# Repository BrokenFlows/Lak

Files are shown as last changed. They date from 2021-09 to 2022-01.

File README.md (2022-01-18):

# Lak
Lak is a 40-key macro ~~pad~~ board

Lak Photo

I primarily type using a small, split, keyboard called [Ishka](https://github.com/BrokenFlows/Ishka).
While very ergonomic, and designed specifically for my hands, it requires two hands to use effectively.
So, I designed Lak for situations where I may have one hand on a mouse and still want to use some keyboard functions.

The stl files in this repository, with the rest of the physical components outlined in the bill of materials, can be used to create a 40-key programmable macroboard.

Lak is a hand-wired keyboard project powered by a [nice!nano](https://nicekeyboards.com/nice-nano) and [ZMK](https://zmk.dev).
Instructions on where to find the shield config, keymap, and a prebuilt `.uf2` can be found in my [zmk-lak repo](https://github.com/BrokenFlows/zmk-lak).

## Instructions

The following instructions will provide details on how to assemble the project as well as covering the materials required.

The [BoM](#Bill-of-Materials) outlines this further, but by way of materials, the project requires some readily available keyboard components, some custom 3D printed components, and a nice!nano microcontroller which (at the time of writing) is available at somewhat frequent but irregular intervals.

The [assembly](#Pre-Wiring) of the project will require some soldering which won't be difficult but may be time-consuming.
If you're new to soldering, I recommend checking out [this YouTube playlist of soldering how-to videos](https://youtube.com/playlist?list=PLYbmtQOxpiujxQlyrUXsafJzl7sxFdSJW).

### Hardware

The [tools](#Tools) and [materials](#Bill-of-Materials) will be used to assemble the final product, shown above. Once you have acquired the items required, you can follow the steps outlined in the [assembly](#Pre-Wiring) section.

#### Tools
- Soldering Iron
- Solder Wire
- 3D Printer/ 3D Printing Service/ or some means of mimicking [the case and parts](./stls/) listed below
- Scissors/ wire cutter
- Glue/ Hot Glue Gun
- Electrical Tape
- **Optional:** wire stripper

#### Bill of Materials
Item # | Quantity | Part Name                                                 | Description
------:|---------:|:----------------------------------------------------------|-------------
1      | 1        | [lak case.stl](./stls/lak_case.stl)                       | The case and integrated switch plate for the keyboard
2      | 1        | [lak sled.stl](./stls/lak_sled.stl)                       | The housing for the nice!nano at the back of the case
3      | 1        | [lak base plate.stl](./stls/lak_base_plate.stl)           | The bottom cover for the keyboard, to protect the wiring once built
4      | 40       | [MX-Style Switches](https://kbdfans.com/collections/gateron-swithes/products/gateron-swtich-3pin-or-5pin?variant=35765200333) | MX-style key switches will serve as the button mechanism
5      | 40       | [MX-Style Keycaps](https://www.adafruit.com/product/5039) | MX-style keycaps, a uniform profile will work best
6      | 40       | [Diodes](https://www.adafruit.com/product/1641)           | Diodes for creating the key matrix
7      | 24       | [Wires](https://www.ebay.ie/itm/232901601951)             | Lengths of insulated solid-core wire to create the key matrix
8      | 1        | [nice!nano](https://nicekeyboards.com/nice-nano)          | The nice!nano microcontroller will serve as the brains of the project and connect to your computer
9      | 1        | [301230 Lithium Polymer Battery](https://www.aliexpress.com/item/33001770863.html) | Optional: LiPo battery to enable wireless usage

The above BoM lists uniform profile keycaps and links to relegendable keycaps. I used a mixture of both of the following in my build:
- [Relgendable MX-Style Keycaps](https://www.adafruit.com/product/5039)
- [DSA Blank Keycaps](https://kbdfans.com/collections/dsa-profile/products/dsa-blank-keycaps-1u-10pcs)

If mixing and matching, or just getting one set, be sure to have 40 keycaps available for your build.

#### 3D Printing
I recommend 3D printing the stl files at the following settings:
Setting         | Value
:---------------|-----:
Filament        | PLA
Nozzle Diameter | < 0.4 mm
Layer Height    | < 0.2 mm
Infill          | 20% <
Supports        | On

#### Pre-Wiring
1. Insert the 40 switches into the case — the top of the switches should be on the shorter side relative to the plate.
2. At this point the keycaps can be placed on top of the switches. If using relegendable keycaps, insert the paper legends before placing the keycaps.

#### Wiring
This guide will go into light detail about the specifics of hand-wiring this keyboard.
This should be sufficient if you're familiar with the process of hand-wiring a keyboard.

The following guides will provide greater detail about the process of hand-wiring, though not the specifics of this board.
These may be helpful if it is your first time hand-wiring a keyboard:

- [QMK Firmware's _Hand-Wiring Guide_](https://github.com/qmk/qmk_firmware/blob/master/docs/hand_wire.md#wiring-the-matrix)
- [RoastPotatoes' _How to hand wire a Plank_](https://blog.roastpotatoes.co/guide/2015/11/04/how-to-handwire-a-planck/#switches)
- [Matt3o.com's _Hand-wiring a custom keyboard_](https://matt3o.com/hand-wiring-a-custom-keyboard/)

---

To start, bend the legs of a diode so that it can hook onto a switch pin and the leg can continue along the row of keys, as seen in the following picture.
Take care to orientate the cathode of the diode (the side marked with a black strip) away from the switch and towards the other diodes.
This is a `col2row` diode direction in the ZMK firmware.

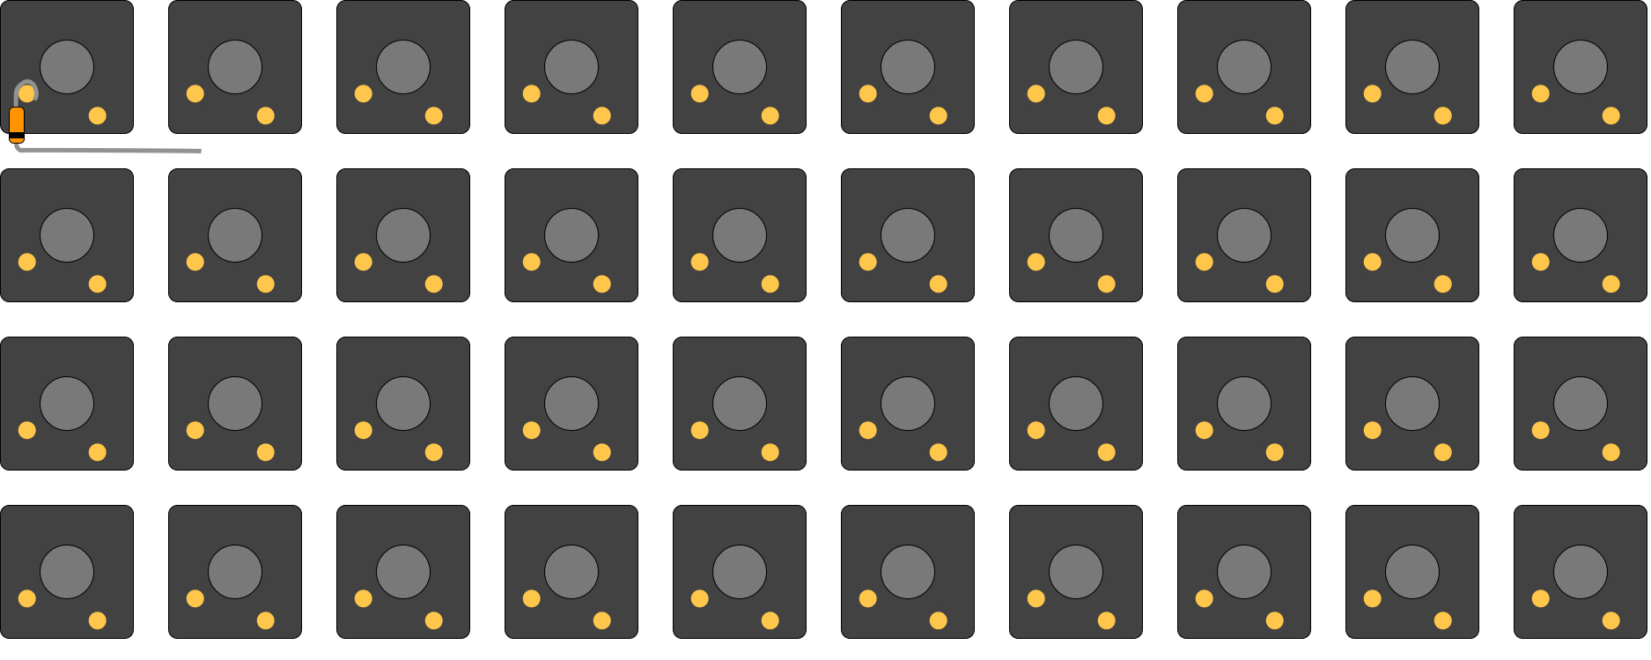
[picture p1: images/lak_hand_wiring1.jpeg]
Picture showing a diode hooked onto a switch pin with one leg while the other leg carries on towards the next switch


At this point solder the diode to the switch pin. Then prepare another diode the same way at the next switch over.

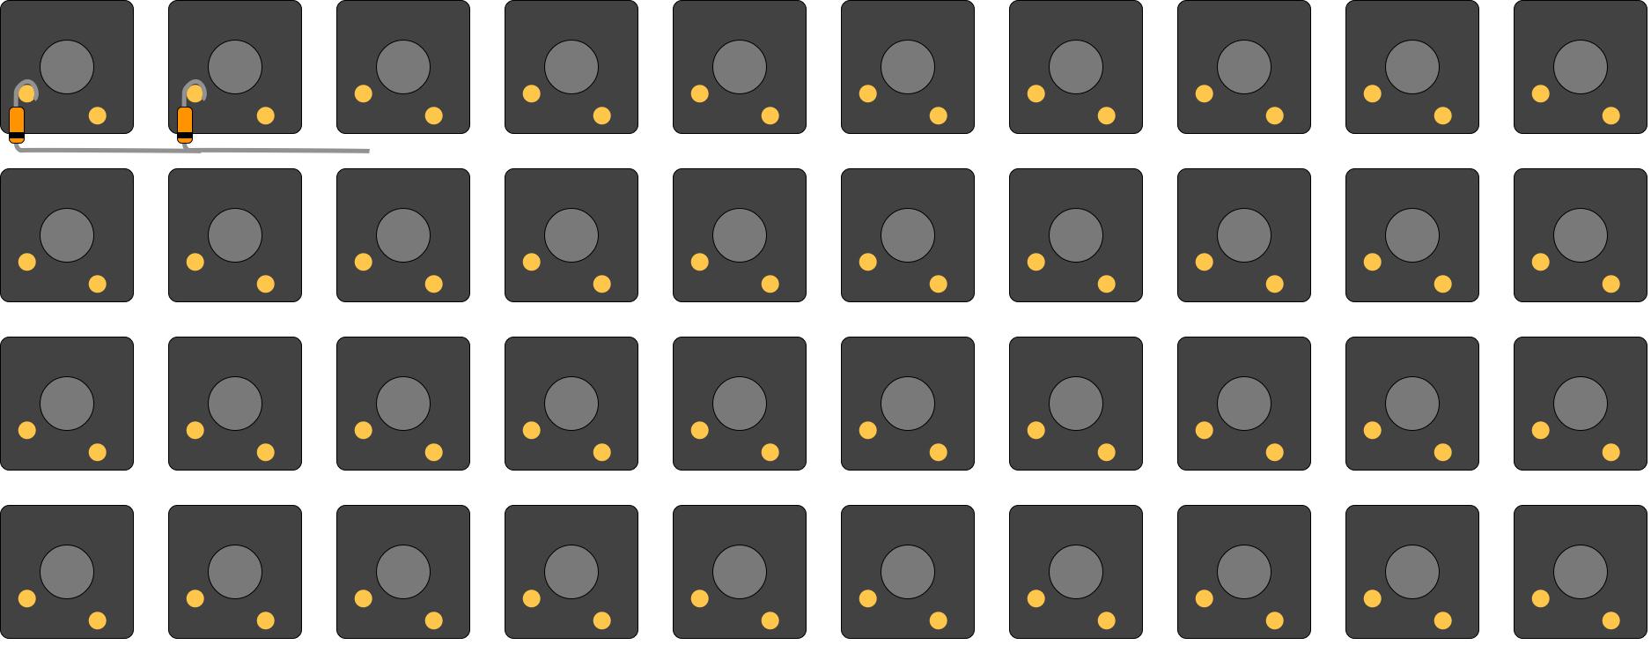
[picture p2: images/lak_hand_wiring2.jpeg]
Picture showing two diodes hooked onto switch pins with one leg while the other leg carries on towards the next switches


Once both switches are soldered to the switch pins, solder the diode legs together along the row where the legs meet.

Carry on, repeating this process until there is one diode connected to each switch and all diodes in a row are connected also.

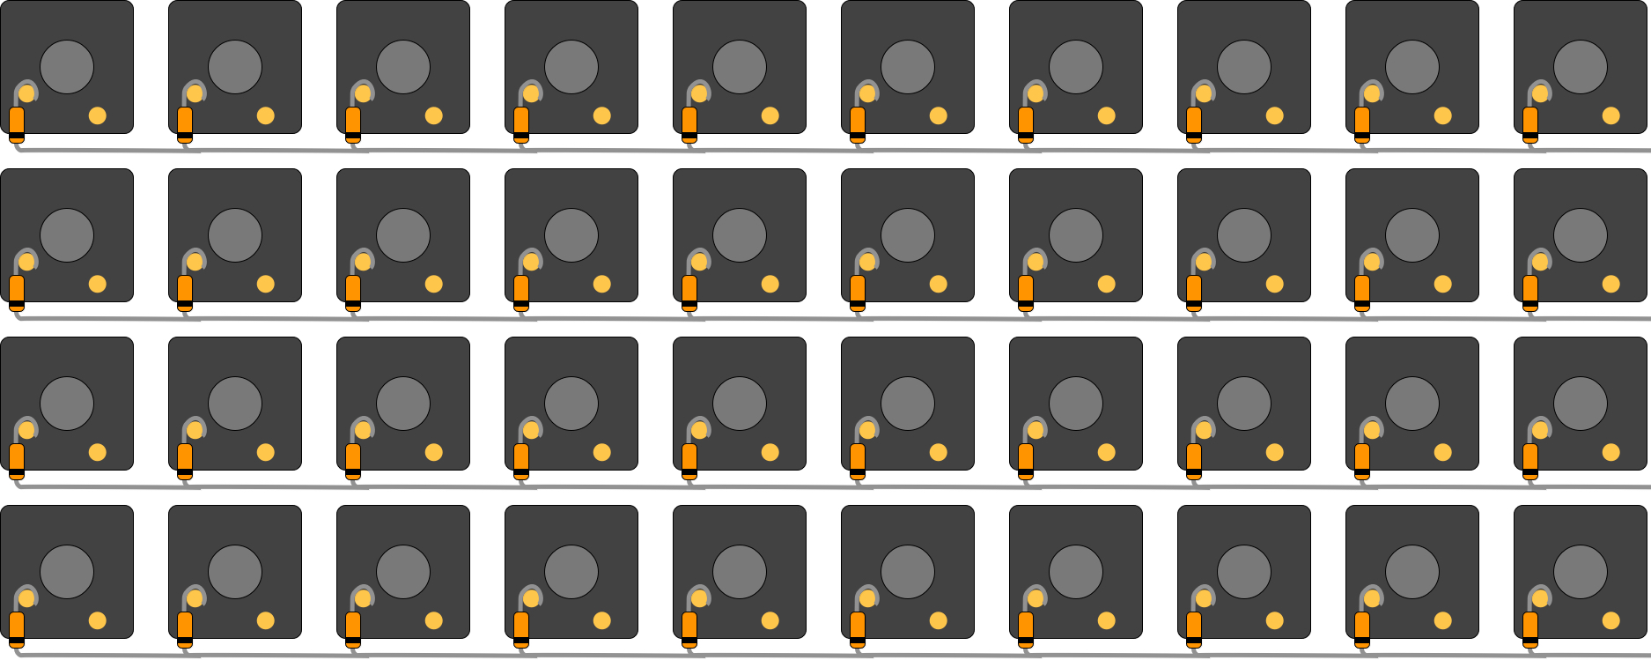
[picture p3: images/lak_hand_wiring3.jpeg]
Picture showing 40 diodes connected to switches in rows of 10


Photo showing 40 diodes connected to switches in rows of 10
 
This completes the rows of the matrix. 

---

Next we connect the columns of the matrix with lengths of wire.
This can be done with three wires per column, one between each pair of switch pins, or with one long wire stripped where it passes the switch pins.

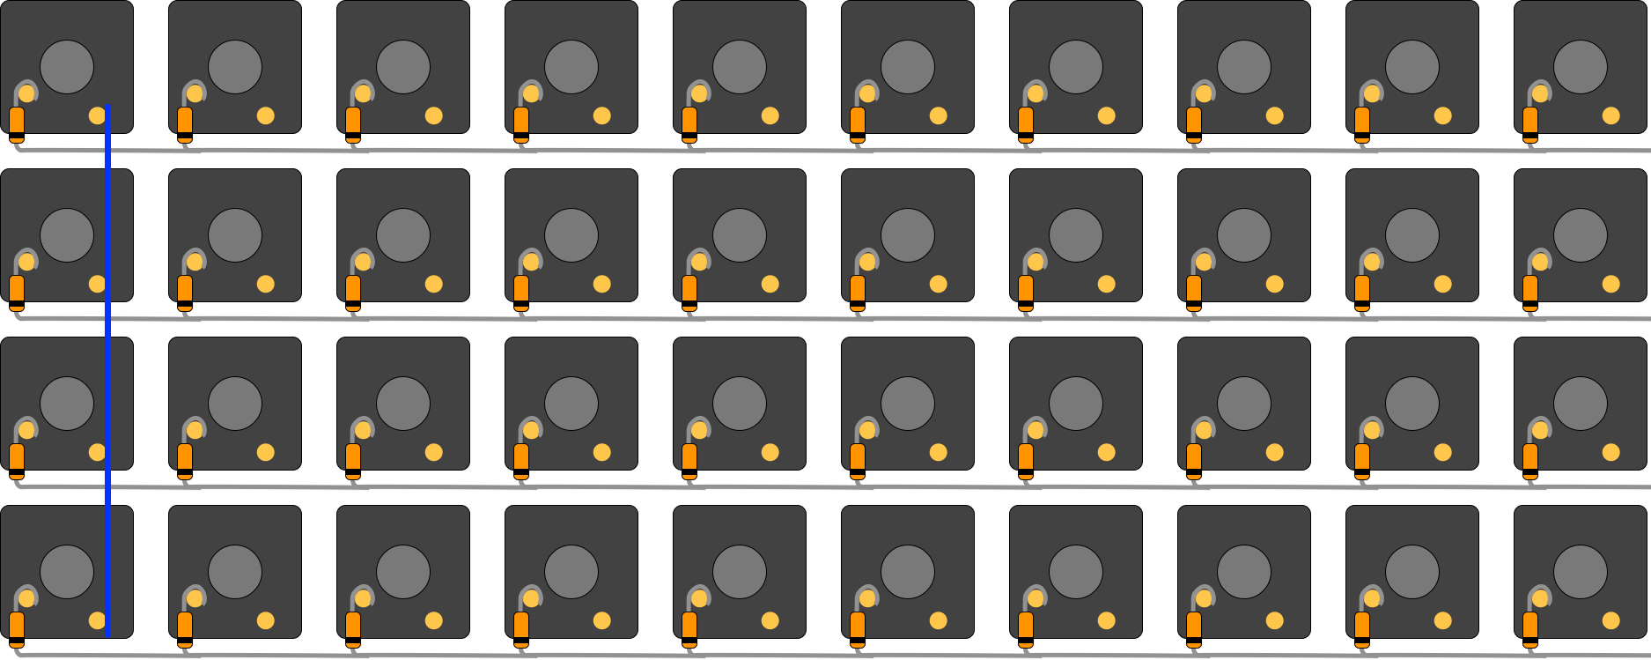
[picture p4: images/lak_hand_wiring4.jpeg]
Picture showing a wire connecting switches in one column together by the remaining pins on the switches


It is important that no bare wire touch any metal in the rows.
This is the benefit of using insulated wire.
If using uninsulated wire, using electrical tape or similar to mask where wires would meet.

Solder the wire in place where it passes each pin.
Whether using three wires or one length with stripped sections, there should be four solder joint per column.

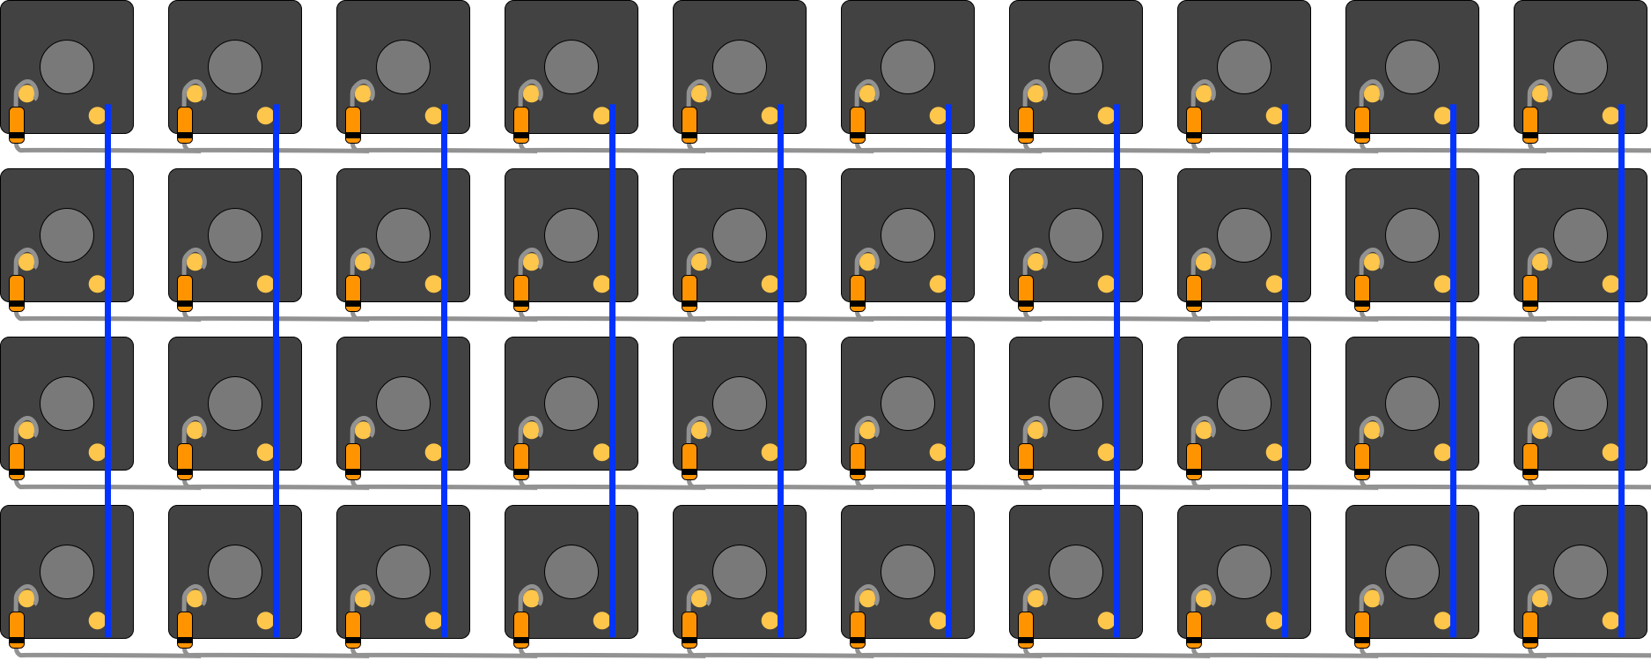
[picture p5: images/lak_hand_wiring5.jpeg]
Picture showing wires connecting switches in each column together by the remaining pins on the switches


Photo showing wires connecting switches in each column together by the remaining pins on the switches

This completes the columns of the matrix, and therefore the entire switch matrix.

---

To finish the wiring, we must connect the correct pins on the nice!nano to points on this matrix.
The following image shows a labelled diagram of a nice!nano and its pins, as well as a diagram showing which part of the matrix connects to which pin of the nice!nano.

It is important to note the frames of reference for each diagram:
- The diagram of the nice!nano shows the top, bumpier, side. If flipping the nice!nano, you will need to pay attention to wire the correct pins.
- The diagram of the keyboard matrix show the top as the furthest side of the keyboard from you when in use; this can be seen by the cutout in the case for the nice!nano.

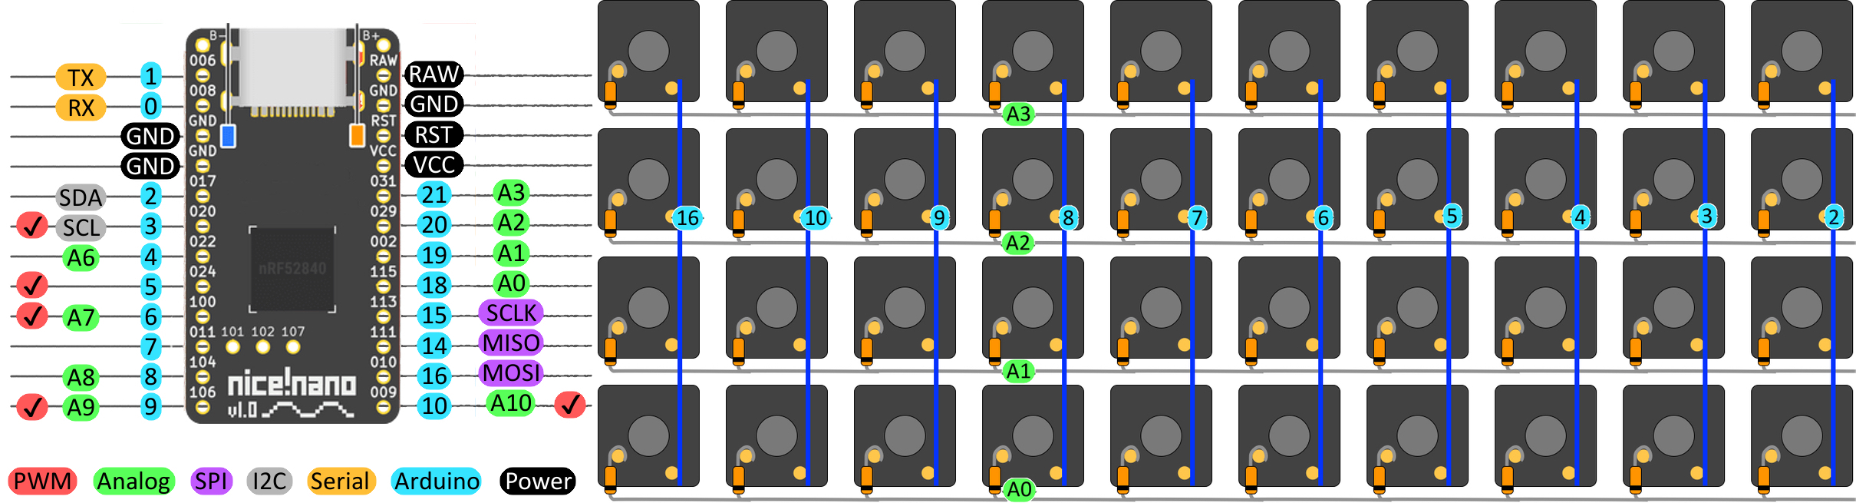
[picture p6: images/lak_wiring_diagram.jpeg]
Labelled pinout diagram for the nice!nano


Using more wire, solder connections between the pins of the nice!nano and the matching labels of the keyboard matrix.
Any point along the columns will make a valid connection.
Any point "below" the black line of the diode will make a valid connection for the rows.

Once all other wiring is done, the optional battery can be soldered to the nice!nano's B+/- pins.
The black wire on the battery connects to the B- pin, the red wire to the B+ pin.

**IMPORTANT**
Before [sealing the case](#Fit-and-Finish), we must flash the nice!nano with [firmware](#Firmware).
This serves two purposes:
- Unless the firmware is running on the nice!nano, we cannot re-flash the nice!nano without physical access to it
- We can validate the wiring and make any necessary corrections while we still have easy access to the wires

If there are any missing or mixed signals, revisit the earlier steps on how to wire the keyboard and double check your work against the instructions.
Once the case is sealed, it won't be desirable to revisit earlier steps.

#### Firmware

You can find a ready-to-flash firmware file in the [`zmk-lak` GitHub repo](https://github.com/BrokenFlows/zmk-lak).

In that repo, there are instructions on how to:
- Flash the `.uf2` file
- Create your own custom keymap

Once you have verified your wiring, feel free to make your own keymap with keyboard shortcuts or F-keys to trigger macros on your computer.
It's important to keep some combo of keys available for the bootloader binding.
The bootloader combo will be your only way to re-flash the keyboard once you've sealed it and you cannot access the pins on your nice!nano.

#### Fit and Finish
With all wiring done, we can close up the case.

First, you may want to apply some electrical tape above where the sled will sit, as to avoid any short-circuits once the case is sealed.
Then, put the nice!nano in the sled, flat side to the bottom of the sled, and test how the sled sits in the cut-out of the case.
Once you're sure it it fits properly, glue the sled in place in this cut-out.

If you are using a battery, you may want to find some space to secure that within the case.

Then, test the fit of the bottom plate of the case.
Again, once you're happy with the fit, glue it in place.

Finally, customise the keycaps to your liking.

---

You've just completed the build.
Congrats!
I hope that you find it useful.
You'll likely want to update the keymap over time, as your needs or preferences change, but for now you're ready to go!

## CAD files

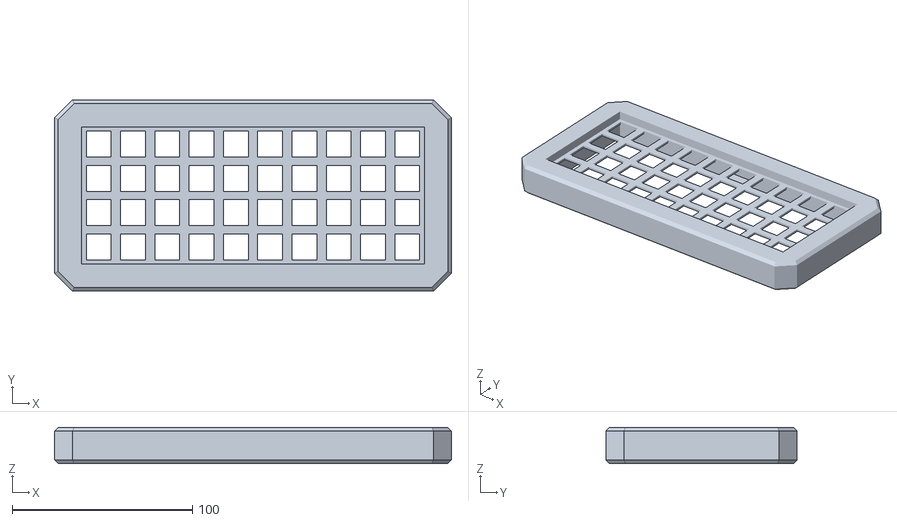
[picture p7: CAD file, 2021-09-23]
stls/lak_case.stl
220.0 x 106.0 x 20.0

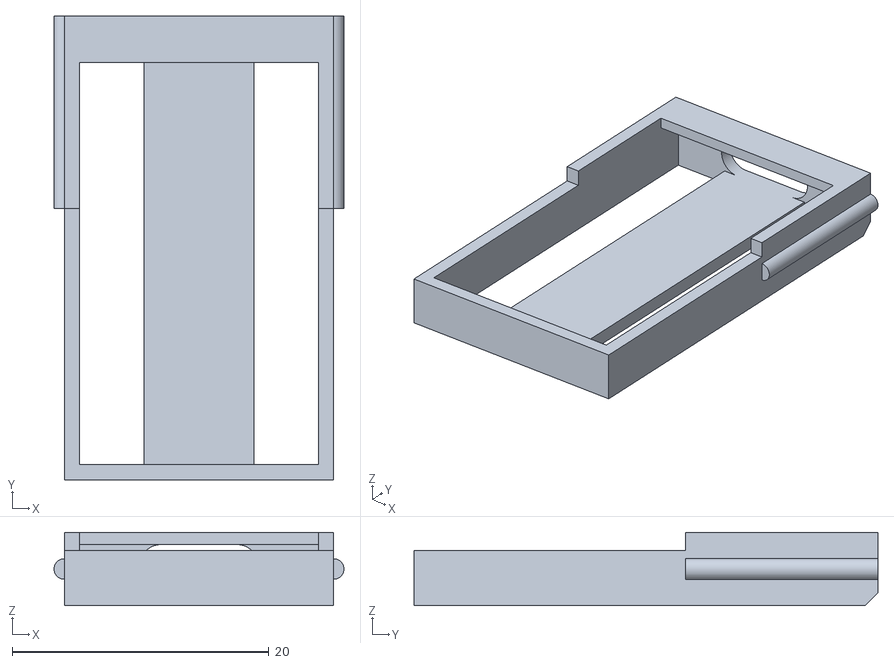
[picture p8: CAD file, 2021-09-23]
stls/lak_sled.stl
22.6 x 36.1 x 5.70

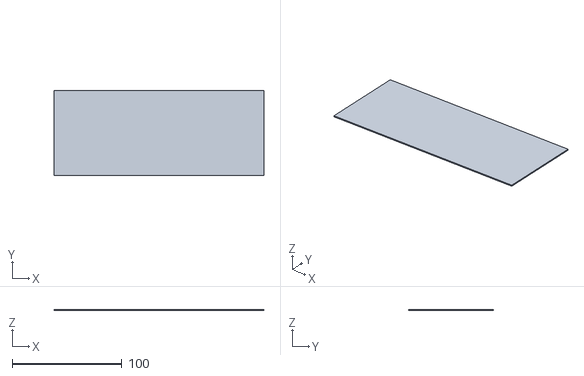
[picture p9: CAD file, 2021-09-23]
stls/lak_base_plate.stl
191.6 x 77.6 x 1.00

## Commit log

2021-09-23 adds a bit more height to the case to leave room for wiring and sled
    [lak case.stl]
2022-01-05 adds photos of wiring and updates README
2022-01-05 adds more details about hand-wiring as well as links to more resources on the subject
2022-01-05 adds note about diode orientation to the README
2022-01-06 adds brief section about n!n wiring to README
2022-01-06 adds notes about wiring the matrix to the n!n
2022-01-06 adds tape to tools and describes process of sealing case
2022-01-07 adds warning to check wiring before closing case.
2022-01-17 improves wording at the end of the wiring section
2022-01-17 fixes tupo in BoM table
2022-01-18 changes stl file names to link better
    [lak_base_plate.stl, lak_case.stl, lak_sled.stl]
